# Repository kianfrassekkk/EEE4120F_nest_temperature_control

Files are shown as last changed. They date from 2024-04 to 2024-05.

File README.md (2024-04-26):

# Yellow-Billed Hornbill Nest Microclimate Monitoring & Control System
## EEE4113F - University of Cape Town
### Kian Frassek (FRSKIA001) | Piwani Nkomo (NKMPIW001) | Khaya Sitaki (STKKHA001) | Danté Webber (WBBDAN003)
###
The aim of this project is to address the current challenges around the breeding of Yellow-Billed Hornbills in the Kalahari, South Africa.
A recent increase in climate temperatures is causing the artificial nest boxes to overheat, causing the hornbills to frequently
abandon breeding attempts. As a result of this, experts have predicted that the Yellow-Billed Hornbills will go extinct in the next 
50 years. Our system will monitor temperature and humidity data in the nest, as well as implement some temperature control 
to the nest.

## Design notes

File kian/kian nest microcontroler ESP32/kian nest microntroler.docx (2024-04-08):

# PCB board with integrated microcontroller, temperature, humidity, and wireless communication in a yellow-billed hornbill's nest.

# Introduction

This subsection contains information about the PCB that will be placed into the bird's nest. This PCB will have a microcontroller, temperature and humidity sensors, a method of storing data, and a means of wirelessly transmitting that data to an external PCB. This report will encompass requirements, detailed specifications, along with further research on components that could be utilized and explanations for why they were disregarded or selected.

# Requirements

This section provides a brief description of the requirements for our board. It is important to remember that I am trying to build a PCB board that fits into a yellow-billed hornbill's nest, which will be in various locations around the Kalahari. Must be able to fit in a nest with space for birds.

- Must measure temperature.
- Must be able to measure humidity.
- Must not disturb the birds.
- Must have the necessary microcontroller as the main Brians of the pcb board
- Must be able to send data (preferably wirelessly)
- Must be able to store data on the pcb board insert
- Deal with the environment e.g. heat, sand.
- Must last a reasonable amount of time.
- There must be able to be powered from the solar panel system already provided.

# Specification

Requirement from which the specification is derived | Information regarding the requirements | Values associated with the requirements | Numerical values that my design will need to meet. | What temperature the chip must be able to withstand in degrees Celsius | Accuracy of the component required. | Cost
Must measure temperature. | In order to track if our control system is working as well as use control feedback loops we need an accurate measure of temperature. | Temperatures in the Kalahari Desert can range from about -20 to 50 degrees Celsius (these values are higher than most values found online; I decided to increase the values to ensure I am within a realistic range). This means the nest could experience temperatures in the range of -20 to 60 degrees Celsius due to the closed environment. | This means my temperate senser must be able to masher temerities in the range of -20 to 60 degrees Celsius. | -20 to 60 | The temperature of the nest needs to remain below 50°C. This means I'll need an accuracy of about 1 decimal point to ensure we stay below 50°C. However, the more accurate this is, the better, as it will enable the researchers to have more precise data for their research. | Temperature sensors should be a very small part of this board and for that reason, should be inexpensive. I am allocating about 0.5% of my total budget to them.
Must be able to measure humidity. | Help get a better understanding of what's going on within the nurse humidity senses will be required | Can go from 20% to 80 % in the Kalahari. The nest conditions may be worse due to the closed off environment. | The humidity sensor should be able to measure humidity between a range of 10 to 90% humidity. | -20 to 60 | For research purposes, greater accuracy is preferred; however, intervals changing every 1% would suffice. | allocating about 0.5% of my total budget to them.
Must not disturb the birds. | If the birds are disturbed either via noise or air flow, they will reject the nests | about 15 dB at their most sensitive frequencies (1,000 and 3,500 Hz); sounds must be about 39 dB at their least sensitive frequencies (250 and 8,000 Hz) (not for the yellow bold hornbill but does give a good indication of what kind of range we need to be operating within) | all commands should remain below 15 dB | N/A | N/B | N/A
Must have the necessary microcontroller as the main Brians of the pcb board. | require a microcontroller which can keep run the bour while not using to much power | Enough pins to support all items in the board will need SPI and ice grid C capabilities as well as a wireless data transfer in built or the capabilities to communicate with their wireless data transfer chip | (coming back) | -20 to 60 | N/A | 30 %
Must be able to send data (preferably wirelessly) | like the user to have the capability of pressing a button on a separate device and receiving all the temperature data from the PCB board in the nest. | The user has been able to reach the nest The user has been able to access the nest and retrieve data manually from it on a regular basis. However, we would only see a purpose in implementing this device if they can obtain the data from a distends greater than 7 m. | | -20 to 60 | This device needs to be able to accurately send data to 1 decimal point worth of accuracy. | Up to 10%
Must be able to store data on the pcb board insert | the data must be able to be stored on the device as the researchers will only return to the nest on a weekly or monthly basis | the data must be able to store at least two-month worth of data on a storage device | two months | -20 to 60 | all data must be able to be stored to the create accuracy as stated for those previous sections | Up to 10% of bouget
Deal with the environment e.g. heat, sand.

# Sure, please provide the text selection that you would like me to format nicely.

FRSKIA001 report for the pcb board in the nest

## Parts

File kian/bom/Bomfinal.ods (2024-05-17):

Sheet: kian_nest_microcontroler
Reference | Value | Footprint | Datasheet | LCSC | Sim.Device | Sim.Pins | Sim.Type | cost | cost | where | Qty
e?() | HKD SD CARD READ/WRITE MODULE |  |  |  |  |  |  | 19 |  | https://www.communica.co.za/products/hkd-sd-card-read-write-module?variant=39359979651145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 | 1
J1, J2 | Conn_01x20_Pin |  | ~ |  |  |  |  | 24 |  | brenden | 2
J4, J5 | Conn_01x20_Socket |  | ~ |  |  |  |  | 20 |  | brenden | 2
Q1 | NMOS |  | https://ngspice.sourceforge.io/docs/ngspice-manual.pdf |  | NMOS | 1=D 2=G 3=S | VDMOS | 10 | 10 | brenden | 1
SW1 | SW_MEC_5E |  | http://www.apem.com/int/index.php?controller=attachment&id_attachment=1371 |  |  |  |  | 2 |  | brenden | 1
U1 | PICO_W | footprint:LCC-40_L51.0-W21.0-P2.54-BL_RP2040-BASED | https://datasheets.raspberrypi.com/pico/pico-datasheet.pdf | C7203003 |  |  |  | 150 |  | https://www.pishop.co.za/store/raspberry-pi-pico-wh-with-pre-soldered-headers?keyword=pico%20w&category_id=0 | 1
U2 | sht31-d-dig-temp-hum-sens |  | file:///C:/Users/kianf/Downloads/SHT33-DIS.PDF |  |  |  |  | 125 |  | https://www.communica.co.za/products/hkd-gy-sht31-d-dig-temp-hum-sens?variant=44762824442156 | 1
U3-U5 | MCP9700x-HLT | Package_TO_SOT_SMD:SOT-353_SC-70-5 | http://ww1.microchip.com/downloads/en/devicedoc/20001942g.pdf |  |  |  |  | 10 |  | brenden | 3
U6 | DHT22 | footprint:SENSOR-TH_HAIGU_DHT22 |  | C2880291 |  |  |  | 79 |  | https://www.communica.co.za/products/hkd-temp-humd-dht22-sensor?variant=44293598052652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 | 1
 |  |  | 0

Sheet: kian_recever_microcontroler_sub
Reference | Value | Footprint | Datasheet | LCSC | Sim.Device | Sim.Pins | Sim.Type | cost | cost | where | Qty
e1 | HKD SD CARD READ/WRITE MODULE |  |  |  |  |  |  | 19 |  | https://www.communica.co.za/products/hkd-sd-card-read-write-module?variant=39359979651145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 | 1
J1, J3 | Conn_01x20_Pin |  | ~ |  |  |  |  | 24 |  | brenden | 2
J2, J4 | Conn_01x20_Socket |  | ~ |  |  |  |  | 20 |  | brenden | 2
Q1 | NMOS |  | https://ngspice.sourceforge.io/docs/ngspice-manual.pdf |  | NMOS | 1=D 2=G 3=S | VDMOS | 10 | 10 | brendon | 1
SW1 | SW_MEC_5E |  | http://www.apem.com/int/index.php?controller=attachment&id_attachment=1371 |  |  |  |  | 2 |  | brendon | 1
U1 | LCD |  |  |  |  |  |  | 58 |  | https://www.robotics.org.za/LCD1602-WB-33V-I2C | 1
U3 | PICO_W | footprint:LCC-40_L51.0-W21.0-P2.54-BL_RP2040-BASED | https://datasheets.raspberrypi.com/pico/pico-datasheet.pdf | C7203003 |  |  |  | 150 |  | https://www.pishop.co.za/store/raspberry-pi-pico-wh-with-pre-soldered-headers?keyword=pico%20w&category_id=0 | 1

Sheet: final
section |  |  |  |  |  |  |  |  | voltage |  |  | current |  |  | power |  |  |  | constent or time on of
 | ref | what | where | Quntety | cost | net cost | things that don’t need to be included | data sheet | min | typ | max | min | typ | max | min | typ | max | value to ues in watts
nest micocontroler | e?() | HKD SD CARD READ/WRITE MODULE | https://www.communica.co.za/products/hkd-sd-card-read-write-module?variant=39359979651145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 | 1 | 19 | 19 | 19 | 0 | 3,3 | 3,3 | 5 | 0,02 | 0,07 | 0,1 | 0,066 | 0,231 | 0,5 | 0,05775 | onle od when sending data. Will do this when I am near to filling the chash memory
 | J4, J5 | Conn_01x20_Socket | brenden | 1 | 20 | 20 | 0 | ~ | 0 | 0 | 0 | 0 | 0 | 0 | 0 | 0 | 0
 | Q1 | NMOS | brenden | 1 | 20 | 20 | 0 |  | 3,3 | 3,3 | 3,3 | 0,000033 | 0,000033 | 0,000033 | 0,0001089 | 0,0001089 | 0,0001089 | 0,000027225 | when the 3.3 power lines are ternd of
 | SW1 | SW_MEC_5E | brenden | 1 | 2 | 2 | 0 | http://www.apem.com/int/index.php?controller=attachment&id_attachment=1371 | 3,3 | 3,3 | 3,3 | 0,000066 | 0,000066 | 0,000066 | 0,0002178 | 0,0002178 | 0,0002178 | 0 | onlle when the button it presed
 | U1 | ESP32 | https://www.pishop.co.za/store/raspberry-pi-pico-wh-with-pre-soldered-headers?keyword=pico%20w&category_id=0 | 1 | 159 | 159 | 159 | https://datasheets.raspberrypi.com/pico/pico-datasheet.pdf | 5 | 5 | 5 | 0,005 | 0,025 | n/a | 0,025 | 0,125 | #VALUE! | 0,05 | In this senero typ in in power mode and min is in sleep mode worst case I can onlie get it to sleep for 3/4 of the time.
 | U2 | sht31-d-dig-temp-hum-sens | https://www.communica.co.za/products/hkd-gy-sht31-d-dig-temp-hum-sens?variant=44762824442156 | 1 | 125 | 125 | 125 | file:///C:/Users/kianf/Downloads/SHT33-DIS.PDF | 3,3 | 3,3 | 3,3 | 0 | 0,0000017 | 0 | 0 | 0,00000561 | 0 | 0,00000561
 | U3-U5 | MCP9700x-HLT | brenden | 3 | 10 | 30 | 0 | http://ww1.microchip.com/downloads/en/devicedoc/20001942g.pdf | 3,3 | 3,3 | 3,3 | 0 | 0,000006 | 0,000012 | 0 | 0,0000198 | 0,0000396 | 0,0000594 | going to use 3 (alredy included in calculations)
 | U6 | DHT22 | https://www.communica.co.za/products/hkd-temp-humd-dht22-sensor?variant=44293598052652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 | 1 | 79 | 79 | 79 | file:///C:/Users/kianf/Downloads/DHT22%20(1).PDF | 3,3 | 3,3 | 3,3 |  | 0,00005 | 0,0012 | 0 | 0,000165 | 0,00396 | 0,00111375 | typ is not mesuring and max is whil meshring
total |  |  |  |  | 434 | 454 | 382 |  |  |  |  |  |  |  |  |  |  | 0,108955985
recever | e1 | HKD SD CARD READ/WRITE MODULE | https://www.communica.co.za/products/hkd-sd-card-read-write-module?variant=39359979651145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 | 1 | 19 | 19 | 19 | 0 | 3,3 | 3,3 | 5 | 0,02 | 0,07 | 0,1 | 0,066 | 0,231 | 0,5 | 0,05775 | onle od when sending data. Will do this when I am near to filling the chash memory
 | J1, J3 | Conn_01x20_Pin | brenden | 1 | 24 | 24 | 0 | ~ | 0 | 0 | 0
 | J2, J4 | Conn_01x20_Socket | brenden | 1 | 20 | 20 | 0 | ~ | 0 | 0 | 0
 | Q1 | NMOS | brendon | 1 | 10 | 10 | 10 | https://ngspice.sourceforge.io/docs/ngspice-manual.pdf | 3,3 | 3,3 | 3,3 | 0,000033 | 0,000033 | 0,000033 | 0,0001089 | 0,0001089 | 0,0001089 | 0,000027225 | when the 3.3 power lines are ternd of
 | SW1 | SW_MEC_5E | brendon | 1 | 2 | 2 | 2 | http://www.apem.com/int/index.php?controller=attachment&id_attachment=1371 | 3,3 | 3,3 | 3,3 | 0,000066 | 0,000066 | 0,000066 | 0,0002178 | 0,0002178 | 0,0002178 | 0 | onlle when the button it presed
 | U1 | LCD | https://www.robotics.org.za/LCD1602-WB-33V-I2C | 1 | 58 | 58 | 58 | 0 | 3,3 | 3,3 | 3,3
 | U3 | ESP32 | https://www.pishop.co.za/store/raspberry-pi-pico-wh-with-pre-soldered-headers?keyword=pico%20w&category_id=0 | 1 | 159 | 159 | 159 | https://datasheets.raspberrypi.com/pico/pico-datasheet.pdf | 5 | 5 | 5 | 0,005 | 0,025 | n/a | 0,025 | 0,125 | #VALUE! | 0,036111111 | In this senero typ in in power mode and min is in sleep mode worst case I can onlie get it to sleep for 3/4 of the time.
total |  |  |  |  | 292 | 292 | 248 |  | 3,3 | 3,3 | 3,3 |  | 0,1 |  |  | 0,33 |  | 0,33 | REALY not Sure about this
other |  | HKV HS-TFC1-16GB+ADPT | https://www.communica.co.za/products/hkv-hs-tfc1-16gb-adpt | 2 | 56 | 112 | 112 |  |  |  |  |  |  |  |  |  |  | 0,366138336
 |  | contaner | https://www.takealot.com/o2-store-900ml-lunch-box-with-snack-sections/PLID94527310 | 1 | 99 | 99 | 0
total |  |  |  |  |  | 211 | 112
net cost |  |  |  |  |  | 957 | 742
 |  |  |  |  |  |  |  |  |  |  |  |  |  |  |  | 0.066 | 0.231 | 0.5 | 0.05775 | 0.066 | 0.231 | 0.5 | 0.05775
 |  |  |  |  |  |  |  |  |  |  |  |  |  |  |  | 0 | 0 | 0 |  | 0 | 0 | 0
 |  |  |  |  |  |  |  |  |  |  |  |  |  |  |  | 0 | 0 | 0 |  | 0 | 0 | 0
 |  |  |  |  |  |  |  |  |  |  |  |  |  |  |  | 0.0001089 | 0.0001089 | 0.0001089 | 0.000027225 | 0.0001089 | 0.0001089 | 0.0001089 | 0.000027225
 |  |  |  |  |  |  |  |  |  |  |  |  |  |  |  | 0.0002178 | 0.0002178 | 0.0002178 | 0 | 0.0002178 | 0.0002178 | 0.0002178 | 0
 |  |  |  |  |  |  |  |  |  |  |  |  |  |  |  | 0.025 | 0.125 | #VALUE! | 0.05 | 0.025 | 0.125 | #VALUE! | 0.05
 |  |  |  |  |  |  |  |  |  |  |  |  |  |  |  | 0 | 0.00000561 | 0 | 0.00000561 | 0 | 0.00000561 | 0 | 0.00000561
 |  |  |  |  |  |  |  |  |  |  |  |  |  |  |  | 0 | 0.0000198 | 0.0000396 | 0.0000594 | 0 | 0.0000198 | 0.0000396 | 0.0000594
 |  |  |  |  |  |  |  |  |  |  |  |  |  |  |  | 0 | 0.000165 | 0.00396 | 0 | 0 | 0.000165 | 0.00396 | 0.00111375
 |  |  |  |  |  |  |  |  |  |  |  |  |  |  |  |  |  |  | 0.108955985 |  |  |  | 0.108955985
 |  |  |  |  |  |  |  |  |  |  |  |  |  |  |  | 0.066 | 0.231 | 0.5 | 0.05775 | 0.066 | 0.231 | 0.5 | 0.05775
 |  |  |  |  |  |  |  |  |  |  |  |  |  |  |  | 0.0001089 | 0.0001089 | 0.0001089 | 0.000027225 | 0.0001089 | 0.0001089 | 0.0001089 | 0.000027225
 |  |  |  |  |  |  |  |  |  |  |  |  |  |  |  | 0.0002178 | 0.0002178 | 0.0002178 | 0 | 0.0002178 | 0.0002178 | 0.0002178 | 0
 |  |  |  |  |  |  |  |  |  |  |  |  |  |  |  | 0.025 | 0.125 | #VALUE! | 0.0361111111111111 | 0.025 | 0.125 | #VALUE! | 0.0361111111111111
 |  |  |  |  |  |  |  |  |  |  |  |  |  |  |  |  | 0.33 |  | 0.33 |  | 0.33 |  | 0.33
 |  |  |  |  |  |  |  |  |  |  |  |  |  |  |  |  |  |  | 0.366138336111111 |  |  |  | 0.366138336111111

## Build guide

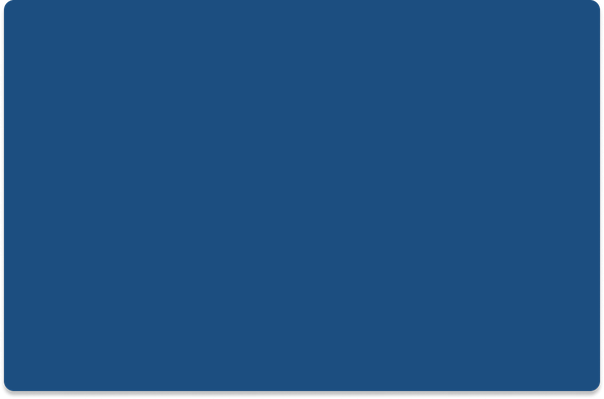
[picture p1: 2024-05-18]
piwani/build/assets/image_2.png

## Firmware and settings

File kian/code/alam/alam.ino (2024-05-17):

// SHT31 - read and set high alert temperature set and clear and test

// see https://sensirion.com/products/catalog/SHT31-DIS-B/
// datasheet and alert mode application note

// to use this code the file Docements>Arduino>libraries>Adafruit_SHT31_Library>Adafruit_SHT31.h
//    requires line 66 editing to comment out the private keyword, e.g
//  //private:
//  this gives the code below access to the private members of class Adafruit_SHT31

#include <Arduino.h>
#include <Wire.h>
#include "Adafruit_SHT31.h"

// parameters for test
#define alertPin 13                       // sht31 alert pin


float highAlertTemperatureSet = 29.0f;    // high alert set
float highAlertTemperatureClear = 26.0f;  // high alert cleared

Adafruit_SHT31 sht31 = Adafruit_SHT31();

// alert interrupt ISR - set alertFlag on change of state
volatile int alertFlag = 0;
void alertISR(void) {
  alertFlag = 1;  // set alert indicator
}

void setup() {
  Serial.begin(115200);
  if (!sht31.begin(0x44)) {  // Set to 0x45 for alternate I2C address
    Serial.println("Couldn't find SHT31");
    while (1) delay(1);
  }
  Serial.println("\n\nsht31 alert limit tests");
  sht31.reset();
  float HighAlertLimitSetTemperature = 60, HighAlertLimitClearTemperature = 0, LowAlertLimitSetTemperature = -10,
        HighAlertLimitSetHumidity = 80, HighAlertLimitClearHumidity = 79, LowAlertLimitSetHumidity = 10;
  // check high and low alert temperatures - should be +60 and -10
  readHighAlertLimitSet(HighAlertLimitSetTemperature, HighAlertLimitSetHumidity);
  Serial.print("high alert limit set temperature (should be 60.00) = ");
  Serial.print(HighAlertLimitSetTemperature);
  Serial.print("  humidity (should be 80.00) = ");
  Serial.println(HighAlertLimitSetHumidity);
  readHighAlertLimitClear(HighAlertLimitClearTemperature, HighAlertLimitClearHumidity);
  Serial.print("high alert limit clear temperature (should be 58.00) = ");
  Serial.print(HighAlertLimitClearTemperature);
  Serial.print("  humidity (should be 79.00) = ");
  Serial.println(HighAlertLimitClearHumidity);
  readLowAlertLimitSet(LowAlertLimitSetTemperature, LowAlertLimitSetHumidity);
  Serial.print("low alert limit set(should be -10.00) = ");
  Serial.print(LowAlertLimitSetTemperature);
  Serial.print("  humidity (should be 22.00) = ");
  Serial.println(LowAlertLimitSetHumidity);

  // set the high temperature alert set and clear
  writeHighAlertLimitSet(highAlertTemperatureSet);  // set high alert temperature level and check it
  readHighAlertLimitSet(HighAlertLimitSetTemperature, HighAlertLimitSetHumidity);
  Serial.print("\nnew high alert limit set temperature  = ");
  Serial.print(highAlertTemperatureSet = HighAlertLimitSetTemperature);
  Serial.print("  humidity  ");
  Serial.println(HighAlertLimitSetHumidity);
  writeHighAlertLimitClear(highAlertTemperatureClear);
  readHighAlertLimitClear(HighAlertLimitClearTemperature, HighAlertLimitClearHumidity);
  Serial.print("new high alert limit clear temperature = ");
  Serial.print(highAlertTemperatureClear = HighAlertLimitClearTemperature);
  Serial.print("  humidity  = ");
  Serial.println(HighAlertLimitClearHumidity);
  uint16_t status = sht31.readStatus();
  Serial.print("status ");
  Serial.println(status, HEX);
  clearStatusRegister();                                               // clear status bits
  setPeriodicDataAcquisitionMode();                                    // set Periodic Data Acquisition Mode
  attachInterrupt(digitalPinToInterrupt(alertPin), alertISR, CHANGE);  // set up interrupt
}

// loop reading temperature and humidity and check for alerts
void loop() {
  uint16_t status = sht31.readStatus();  // read status bits
  Serial.print("status ");
  Serial.print(status, HEX);  // read temperature and humidity
  float temperature, humidity;
  readTempHum(temperature, humidity);
  if (!isnan(temperature)) {  // check if 'is not a number'
    Serial.print("  Temp *C = ");
    Serial.print(temperature);
    Serial.print("\t\t");
  } else {
    Serial.println("Failed to read temperature");
  }
  if (!isnan(humidity)) {  // check if 'is not a number'
    Serial.print("Hum. % = ");
    Serial.println(humidity);
  } else {
    Serial.println("Failed to read humidity");
  }
  // delay checking alertFlag
  long timer = millis();
  bool printedAlert = 0;
  while (millis() - timer < 3000) {
    if (alertFlag) {  // if alert occured
      alertFlag = 0;
      if (!printedAlert) {  // if not already printed
        printedAlert = 1;
        Serial.print("******* alert !! *******  status ");
        status = sht31.readStatus();
        Serial.print(status, HEX);
        Serial.print(" alert pin state  = ");
        int alertPinState = digitalRead(alertPin);
        Serial.println(alertPinState);
        if (alertPinState)
          Serial.println("   *** high temperature alert set !  **** ");
        else
          Serial.println("   *** high temperature alert cleared !  **** ");
        clearStatusRegister();
      }
    }
  }
}

// set up setPeriodic Data Acquisition Mode for alerts
void setPeriodicDataAcquisitionMode(void) {
  sht31.writeCommand(0x2126);  // set repeatability mode
  delay(20);
}

void clearStatusRegister(void) {
  sht31.writeCommand(0x3041);  // clear status register
  delay(20);
}

// read high alert set limit
bool readHighAlertLimitSet(float &temp, float &humidity) {
  Serial.println("reading high alert limit set ");
  uint8_t readbuffer[3] = { 0 };
  sht31.writeCommand(0xE11F);  // read high alert set
  delay(20);
  sht31.i2c_dev->read(readbuffer, sizeof(readbuffer));
  if (readbuffer[2] != crc8(readbuffer, 2)) {
    Serial.println("CRC error!");
    return false;
  }
  Serial.print("readHigAlertLimitSet 0x");
  Serial.print(readbuffer[0], HEX);
  Serial.print(readbuffer[1], HEX);
  Serial.println(readbuffer[2], HEX);
  // temperature convert 9 bit value to 16bit value
  int32_t stemp = ((int32_t)(((uint32_t)((readbuffer[0] & 0x01) << 8)) | readbuffer[1])) << 7;
  // convert from 16bit value
  stemp = 100.0f * ((stemp * 175.0f) / 65535.0f - 45.0f);
  temp = (float)stemp / 100.0f;
  // humidity convert 7 bit value to 16 bit value
  uint32_t shum = (uint32_t)((uint32_t)(readbuffer[0] & 0xFE) << 8);
  humidity = (shum * 100.0f) / 65535.0f;
  return true;
}

// read high alert clear limit
bool readHighAlertLimitClear(float &temp, float &humidity) {
  Serial.print("reading high alert limit clear ");
  uint8_t readbuffer[3] = { 0 };
  sht31.writeCommand(0xE114);  // read high alert set
  delay(20);
  sht31.i2c_dev->read(readbuffer, sizeof(readbuffer));
  if (readbuffer[2] != crc8(readbuffer, 2)) {
    Serial.println("CRC error!");
    return false;
  }
  Serial.print(" 0x");
  Serial.print(readbuffer[0], HEX);
  Serial.print(readbuffer[1], HEX);
  Serial.println(readbuffer[2], HEX);
  // temperature convert 9 bit value to 16bit value
  int32_t stemp = ((int32_t)(((uint32_t)((readbuffer[0] & 0x01) << 8)) | readbuffer[1])) << 7;
  // convert from 16bit value
  stemp = 100.0f * ((stemp * 175.0f) / 65535.0f - 45.0f);
  temp = (float)stemp / 100.0f;
  uint32_t shum = (uint32_t)((uint32_t)(readbuffer[0] & 0xFE) << 8);
  humidity = (shum * 100.0f) / 65535.0f;
  return true;
}

// write high alert set temperature
void writeHighAlertLimitSet(float temp) {
  Serial.print("write high alert limit set ");
  Serial.println(temp);
  // calculate 9 bit value for temperature
  int32_t stemp = (temp + 45.0f) * 65535.0f / 175.0f;
  stemp = stemp >> 7;
  //Serial.print("setHighAlertLimit 0x");
  //Serial.println(stemp,HEX);
  // buffer to set high alert - command is 0x611D
  uint8_t writebuffer[5] = { 0x61, 0x1D, ((stemp >> 8) & 0x01) | 0xCC, stemp & 0xff, 0 };
  writebuffer[4] = crc8(writebuffer + 2, 2);
  //Serial.print(writebuffer[2], HEX);
  //Serial.print(writebuffer[3], HEX);
  //Serial.println(writebuffer[4], HEX);
  sht31.i2c_dev->write(writebuffer, sizeof(writebuffer));  // write updated value
  delay(20);
  sht31.writeCommand(0x2126);  // set repeatability
  delay(20);
}


// write high alert clear temperature
void writeHighAlertLimitClear(float temp) {
  Serial.print("write high alert limit clear ");
  Serial.println(temp);
  // calculate 9 bit value for temperature
  int32_t stemp = (temp + 45.0f) * 65535.0f / 175.0f;
  stemp = stemp >> 7;
  //Serial.print("setHighAlertLimit 0x");
  //Serial.println(stemp,HEX);
  // buffer to set high alert - command is 0x611D
  uint8_t writebuffer[5] = { 0x61, 0x16, ((stemp >> 8) & 0x01) | 0xc8, stemp & 0xff, 0 };
  writebuffer[4] = crc8(writebuffer + 2, 2);
  //Serial.print(writebuffer[2], HEX);
  //Serial.print(writebuffer[3], HEX);
  //Serial.println(writebuffer[4], HEX);
  sht31.i2c_dev->write(writebuffer, sizeof(writebuffer));  // write updated value
  delay(20);
  sht31.writeCommand(0x2126);  // set repeatability
  delay(20);
}

// read low alert set temperature
bool readLowAlertLimitSet(float &temp, float &humidity) {
  Serial.println("reading low alert limit set ");
  uint8_t readbuffer[3] = { 0 };
  sht31.writeCommand(0xE102);  // read low alert set
  delay(20);
  sht31.i2c_dev->read(readbuffer, sizeof(readbuffer));
  if (readbuffer[2] != crc8(readbuffer, 2)) {
    Serial.println("CRC error!");
    return false;
  }
  Serial.print("readLowAlertLimitSet 0x");
  Serial.print(readbuffer[0], HEX);
  Serial.print(readbuffer[1], HEX);
  Serial.println(readbuffer[2], HEX);
  // temperature convert 9 bit value to 16bit value
  int32_t stemp = ((int32_t)(((uint32_t)((readbuffer[0] & 0x01) << 8)) | readbuffer[1])) << 7;
  // temperature convert from 16bit value
  stemp = 100.0f * ((stemp * 175.0f) / 65535.0f - 45.0f);
  temp = (float)stemp / 100.0f;
  // humidity convert 7 bit value to 16 bit value
  uint32_t shum = (uint32_t)((uint32_t)(readbuffer[0] & 0xFE) << 8);
  humidity = (shum * 100.0f) / 65535.0f;
  return true;
}

static uint8_t crc8(const uint8_t *data, int len) {
  /*
   *
   * CRC-8 formula from page 14 of SHT spec pdf
   *
   * Test data 0xBE, 0xEF should yield 0x92
   *
   * Initialization data 0xFF
   * Polynomial 0x31 (x8 + x5 +x4 +1)
   * Final XOR 0x00
   */

  const uint8_t POLYNOMIAL(0x31);
  uint8_t crc(0xFF);

  for (int j = len; j; --j) {
    crc ^= *data++;

    for (int i = 8; i; --i) {
      crc = (crc & 0x80) ? (crc << 1) ^ POLYNOMIAL : (crc << 1);
    }
  }
  return crc;
}

// read data in Periodic Data Acquisition Mode
bool readTempHum(float &temp, float &humidity) {
  uint8_t readbuffer[6];
  sht31.writeCommand(0xE000);  // Fetch Data command
  delay(20);
  sht31.i2c_dev->read(readbuffer, sizeof(readbuffer));
  if (readbuffer[2] != crc8(readbuffer, 2) || readbuffer[5] != crc8(readbuffer + 3, 2))
    return false;
  int32_t stemp = (int32_t)(((uint32_t)readbuffer[0] << 8) | readbuffer[1]);
  // simplified (65536 instead of 65535) integer version of:
  // temp = (stemp * 175.0f) / 65535.0f - 45.0f;
  stemp = ((4375 * stemp) >> 14) - 4500;
  temp = (float)stemp / 100.0f;
  uint32_t shum = ((uint32_t)readbuffer[3] << 8) | readbuffer[4];
  // simplified (65536 instead of 65535) integer version of:
  // humidity = (shum * 100.0f) / 65535.0f;
  shum = (625 * shum) >> 12;
  humidity = (float)shum / 100.0f;
  return true;
}

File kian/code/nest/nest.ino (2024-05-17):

// the nest

//sd card
#include "FS.h"
#include "SD.h"
#include "SPI.h"


#define MAX_BUFFER_SIZE 128           // Buffer size for formatted data
const char* DATA_FILE_NAME = "/test1.txt";

//for senser
#include <Wire.h>
#include <Adafruit_SHT31.h>
Adafruit_SHT31 sht31 = Adafruit_SHT31();

float highAlertTemperatureSet = 25.0f;    // high alert set
float highAlertTemperatureClear = 25.0f;  // high alert cleared

//#include <esp32-hal.h>

struct SHT3xData {
  float temp;
  float humidity;
};


// for sleep mode
//#define BUTTON_PIN_BITMASK 0x200000000 // 2^33 in hex set up the eternal pin trigger

#include "esp_sleep.h"

// setting up timer

#include <ESP32Time.h>

#define uS_TO_S_FACTOR 1000000ULL  /* Conversion factor for micro seconds to seconds */
#define TIME_TO_SLEEP  10     /* Time ESP32 will go to sleep (in seconds) */

ESP32Time rtc;




//pin const
const int ledPin = 2;   // LED pin
const int SDcardpin = 17;

// function for wifi

// Import required libraries
#include "WiFi.h"
#include "ESPAsyncWebServer.h"


// Set your access point network credentials
const char* ssid = "ESP32-Access-Point";
const char* password = "123456789";

AsyncWebServer server(80);


//function to set up SD card

void listDir(fs::FS &fs, const char * dirname, uint8_t levels){
  Serial.printf("Listing directory: %s\n", dirname);

  File root = fs.open(dirname);
  if(!root){
    Serial.println("Failed to open directory");
    return;
  }
  if(!root.isDirectory()){
    Serial.println("Not a directory");
    return;
  }

  File file = root.openNextFile();
  while(file){
    if(file.isDirectory()){
      Serial.print("  DIR : ");
      Serial.println(file.name());
      if(levels){
        listDir(fs, file.name(), levels -1);
      }
    } else {
      Serial.print("  FILE: ");
      Serial.print(file.name());
      Serial.print("  SIZE: ");
      Serial.println(file.size());
    }
    file = root.openNextFile();
  }
}

void createDir(fs::FS &fs, const char * path){
  Serial.printf("Creating Dir: %s\n", path);
  if(fs.mkdir(path)){
    Serial.println("Dir created");
  } else {
    Serial.println("mkdir failed");
  }
}

void removeDir(fs::FS &fs, const char * path){
  Serial.printf("Removing Dir: %s\n", path);
  if(fs.rmdir(path)){
    Serial.println("Dir removed");
  } else {
    Serial.println("rmdir failed");
  }
}

void readFile(fs::FS &fs, const char * path){
  Serial.printf("Reading file: %s\n", path);

  File file = fs.open(path);
  if(!file){
    Serial.println("Failed to open file for reading");
    return;
  }

  Serial.print("Read from file: ");
  while(file.available()){
    Serial.write(file.read());
  }
  file.close();
}

void writeFile(fs::FS &fs, const char * path, const char * message){
  Serial.printf("Writing file: %s\n", path);

  File file = fs.open(path, FILE_WRITE);
  if(!file){
    Serial.println("Failed to open file for writing");
    return;
  }
  if(file.print(message)){
    Serial.println("File written");
  } else {
    Serial.println("Write failed");
  }
  file.close();
}

void appendFile(fs::FS &fs, const char * path, const char * message){
  Serial.printf("Appending to file: %s\n", path);

  File file = fs.open(path, FILE_APPEND);
  if(!file){
    Serial.println("Failed to open file for appending");
    return;
  }
  if(file.print(message)){
      Serial.println("Message appended");
  } else {
    Serial.println("Append failed");
  }
  file.close();
}

void renameFile(fs::FS &fs, const char * path1, const char * path2){
  Serial.printf("Renaming file %s to %s\n", path1, path2);
  if (fs.rename(path1, path2)) {
    Serial.println("File renamed");
  } else {
    Serial.println("Rename failed");
  }
}

void deleteFile(fs::FS &fs, const char * path){
  Serial.printf("Deleting file: %s\n", path);
  if(fs.remove(path)){
    Serial.println("File deleted");
  } else {
    Serial.println("Delete failed");
  }
}

void writeDataToSD(float temp1, float humidity1, float temp2, float humidity2, const char * cause) {
  
  // Initialize RTC (assuming you're using a DS3231 module)
  

  // Get current time from RTC
  
  String formattedTime = rtc.getTime("%A, %B %d %Y %H:%M:%S");
  String dataLine = formattedTime + ", temp1 ," + String(temp1) + ", humd1 ," + String(humidity1) + ", temp2 ," + String(temp2) + ", humd2 ," + String(humidity2) +", wake up reason ," + cause;
  // Check if the file exists
  if (SD.exists(DATA_FILE_NAME)) {
    // File exists, append data with timestamp
    appendFile(SD, DATA_FILE_NAME, "\n");    
    appendFile(SD, DATA_FILE_NAME, dataLine.c_str());
  } else {
    // File doesn't exist, create it with header including time
    writeFile(SD, DATA_FILE_NAME, "Time,Temperature1,Humidity1,Temperature2,Humidity2\n");
    writeFile(SD, DATA_FILE_NAME, dataLine.c_str());
  }
}

//sleep mod function


void wakeup_reason() {
  esp_sleep_wakeup_cause_t wakeup_reason;

  wakeup_reason = esp_sleep_get_wakeup_cause();
  switch (wakeup_reason)
  {
    case ESP_SLEEP_WAKEUP_EXT0 : Serial.println("Wakeup caused by external signal using RTC_IO"); break;
    case ESP_SLEEP_WAKEUP_EXT1 : Serial.println("Wakeup caused by external signal using RTC_CNTL"); break;
    case ESP_SLEEP_WAKEUP_TIMER : Serial.println("Wakeup caused by timer"); break;
    case ESP_SLEEP_WAKEUP_TOUCHPAD : Serial.println("Wakeup caused by touchpad"); break;
    case ESP_SLEEP_WAKEUP_ULP : Serial.println("Wakeup caused by ULP program"); break;
    default :
      Serial.printf("Wakeup was not caused by deep sleep: %d\n", wakeup_reason);
      rtc.setTime(30, 24, 15, 17, 1, 2024);  // 17th Jan 2021 15:24:30
      //rtc.setTime(1609459200);  // 1st Jan 2021 00:00:00
      //rtc.offset = 7200; // change offset value

      break;
  }
}



void onwakeuptimer(){

  Serial.println("timer wake up");

  SHT3xData data = readSHT3(0x44);

  // Print the sensor readings to the serial monitor
    
  Serial.println("sence 1");
  Serial.print("Temperature: ");
  Serial.print(data.temp);
  Serial.print(" °C, Humidity: ");
  Serial.print(data.humidity);
  Serial.println("%");
  float temp1 = data.temp;
  float humd1 =data.humidity;

  

  data = readSHT3(0x45);

  // Print the sensor readings to the serial monitor
  Serial.println("sence 2");
  Serial.print("Temperature: ");
  Serial.print(data.temp);
  Serial.print(" °C, Humidity: ");
  Serial.print(data.humidity);
  Serial.println("%");

  float temp2 = data.temp;
  float humd2 =data.humidity;

  writeDataToSD(temp1,humd1,temp2,humd2, "timer");

}

void onwakeupallarm(){
Serial.println("allarm !!!");
}


bool wifi = false;
void onwakeuperf(){
  wifisetup();
  wifisend();
  int counter =0; 
  wifi = true;
}



//sensers

// Function to read data from SHT31 sensor
SHT3xData readSHT3(uint8_t address) {
  SHT3xData data;
  if (!sht31.begin(address)) {
    Serial.println("Couldn't find SHT31 sensor!");
    return data; // Return empty data if sensor not found
  }
  data.temp = sht31.readTemperature();
  data.humidity = sht31.readHumidity();
  return data;
}
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

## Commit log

2024-04-05 nest microcontroler kikad project
    creating nest microcontroler kikad project.
    This is where the curcit diagram will be mad for the thing in the nest.
    [kian nest microcontroler.kicad_pcb, kian nest microcontroler.kicad_sch]
2024-04-10 added to nest
    finished the nest microcontroller
    [kian nest microcontroler.kicad_sch, kian recever microcontroler subsection.kicad_sch, microcontroler.kicad_sch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]
2024-04-10 resever
    resever is finished
    [microcontroler.kicad_sch]
2024-04-10 bom
    added the bom and the and power section
    [Bomfinal.ods, kian nest microcontroler.csv, kian recever microcontroler subsection.csv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]
2024-05-17 Added code
    [Bomfinal.ods, kian nest microcontroler.kicad_pcb, kian nest microcontroler.kicad_sch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]
